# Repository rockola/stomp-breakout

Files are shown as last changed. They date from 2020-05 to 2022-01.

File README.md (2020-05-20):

# stomp-breakout
3PDT breakout PCB with LED and resistor

* v0.1: initial import, trace between LED anode and resistor missing
* v0.2: board input grounded in bypass
* v0.4: bi-color CA LED (can still use standard LED), optional anti-pop capacitor & resistor

MIT License.

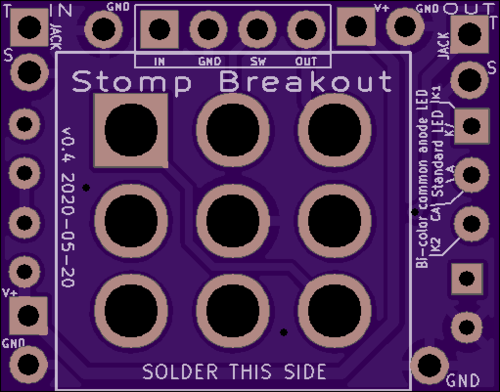
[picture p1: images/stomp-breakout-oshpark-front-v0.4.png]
Front

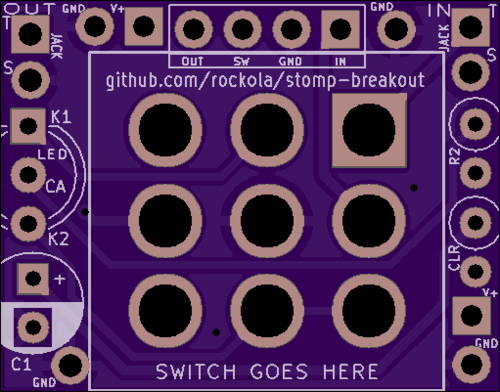
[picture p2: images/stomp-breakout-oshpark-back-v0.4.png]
Back


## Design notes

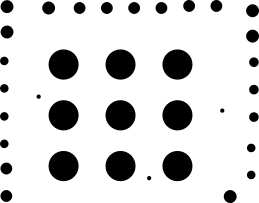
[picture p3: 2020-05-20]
images/stomp-breakout-PTH.drl.png

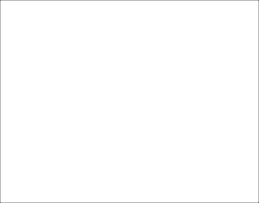
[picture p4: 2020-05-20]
images/stomp-breakout-Edge_Cuts.gm1.png

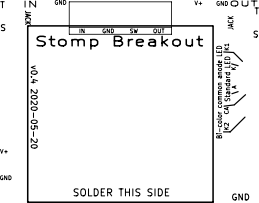
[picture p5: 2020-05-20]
images/stomp-breakout-F_SilkS.gto.png

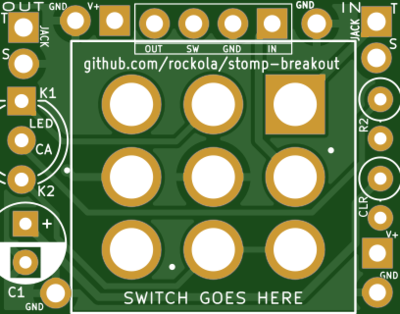
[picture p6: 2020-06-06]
images/v0.4_bottom.png

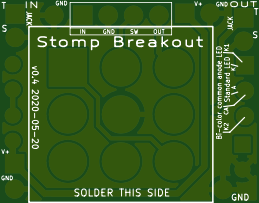
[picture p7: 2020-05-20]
images/top.png

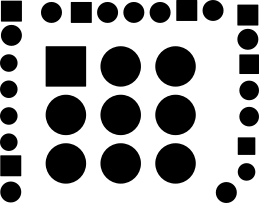
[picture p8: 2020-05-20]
images/stomp-breakout-F_Mask.gts.png

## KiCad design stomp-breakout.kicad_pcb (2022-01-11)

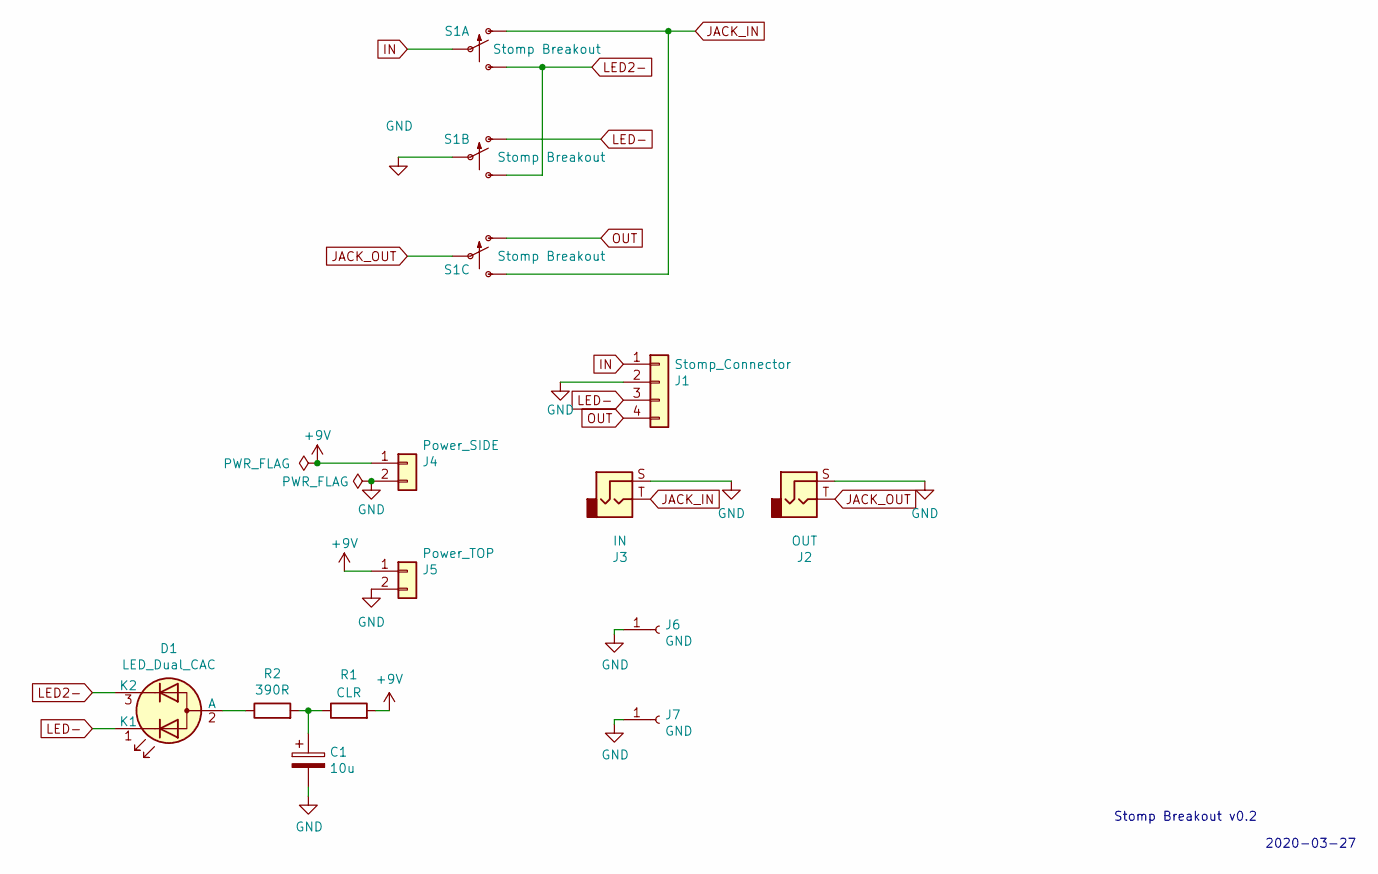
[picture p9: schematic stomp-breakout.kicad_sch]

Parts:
C1: 10u; CP_D5.0_P2.50
D1: LED_Dual_CAC; LED_D5.0mm-3
J1: Stomp_Connector; Stomp_4pin_ALT
J2: OUT; 2PADS_TS_Vertical_NOBORDER
J3: IN; 2PADS_TS_Vertical_NOBORDER
J4: Power_SIDE; Power_Header_2pin_VERTICAL_ALT_NOBORDER
J5: Power_TOP; Power_Header_2pin_TOP_ALT_NOBORDER
J6, J7: GND; 1PAD
R1: CLR; Resistor_0.25W_Standing
R2: 390R; Resistor_0.25W_Standing
S1: Stomp Breakout; 3PDT_Stomp

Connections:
+9V: J4.1 (PWR), J5.1 (PWR), R1.2
GND: C1.2, J1.2 (GND), J2.S, J3.S, J4.2 (GND), J5.2 (GND), J6.1, J7.1, S1.5
IN: J1.1 (IN), S1.2
JACK_IN: J3.T, S1.1 (O), S1.9 (S)
JACK_OUT: J2.T, S1.8
LED2-: D1.3 (K2), S1.3 (S), S1.6 (S)
LED-: D1.1 (K1), J1.3 (SW), S1.4 (O)
unnamed: C1.1, R1.1, R2.2
unnamed: D1.2 (A), R2.1
OUT: J1.4 (OUT), S1.7 (O)

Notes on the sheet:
2020-03-27
Stomp Breakout v0.2

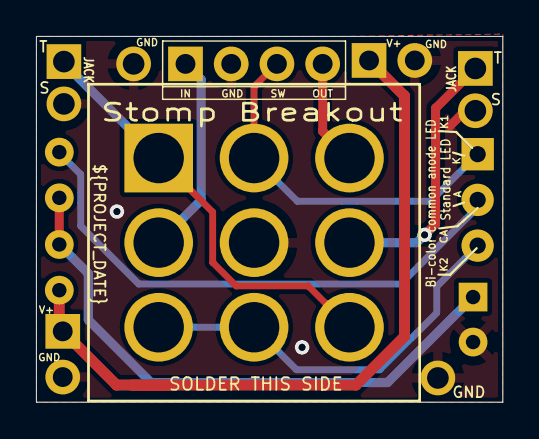
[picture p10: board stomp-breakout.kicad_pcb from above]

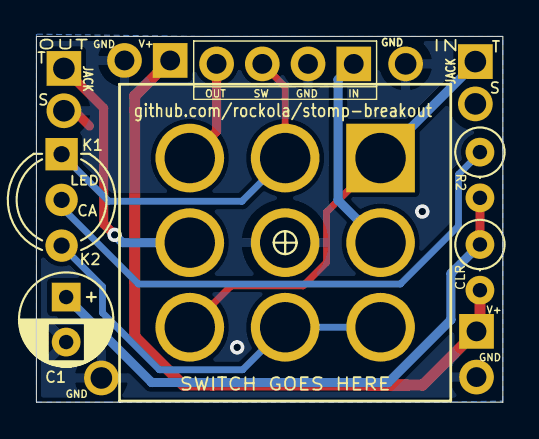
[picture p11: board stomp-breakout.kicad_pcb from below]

Board: 2 copper layers, 25.9 x 20.3 mm, 12 parts (4 on the bottom side), 10 nets.

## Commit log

2020-03-14 0.1: initial import
    [3pdt-basic-B_Cu.gbl, 3pdt-basic-B_Mask.gbs, 3pdt-basic-B_Paste.gbp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]
2020-03-14 initial Gerbers
    [stomp-breakout-B_Cu.gbl, stomp-breakout-B_Mask.gbs, stomp-breakout-B_Paste.gbp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]
2020-03-14 0.1 board images
2020-03-15 0.1: final silkscreen
    [stomp-breakout.kicad_pcb]
2020-03-27 v0.2: board input grounded in bypass
    [stomp-breakout.kicad_pcb, stomp-breakout.sch]
2020-05-20 0.4 Gerbers
    [stomp-breakout-B_Cu.gbl, stomp-breakout-B_Mask.gbs, stomp-breakout-B_Paste.gbp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]
2020-05-20 ignore KiCAD v5 backups
2020-05-20 v0.4: optional bicolor CA LED, anti-pop capacitor & resistor
    [stomp-breakout.kicad_pcb, stomp-breakout.kicad_sch, stomp-breakout.sch]
2020-06-06 images of v0.4 pcb
2022-01-11 updated to KiCad 6.0
    [stomp-breakout.kicad_pcb, stomp-breakout.kicad_sch]
